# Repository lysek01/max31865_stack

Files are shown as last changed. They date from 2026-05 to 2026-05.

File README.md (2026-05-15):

# MAX31865 Stack

A stackable carrier board for the **Adafruit MAX31865** RTD-to-digital
converter. Each board hosts up to **8 MAX31865 modules** and multiple boards
can be stacked on brass standoffs to scale the channel count without changing
the wiring to the host.

<p align="center">
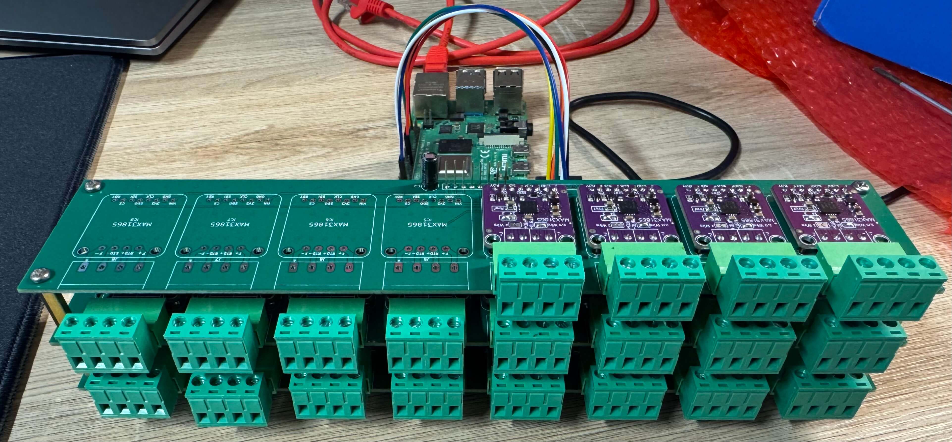
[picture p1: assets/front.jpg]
Front view of the assembled stack
  
</p>

## Overview

Each MAX31865 from Adafruit is an excellent PT100/PT1000 front-end, but
wiring more than a handful of them by hand is tedious and error-prone — every
module needs power, an SPI bus and its own chip-select line.

This project solves that with a carrier PCB that:

- mounts up to **8 plug-in MAX31865 modules** per board,
- brings out a **4-pin pluggable terminal block** per channel for the RTD
  sensor (2/3/4-wire compatible),
- shares one SPI bus across all modules,
- generates individual chip-select signals from a single **PCF8574 I2C
  expander**, so only a handful of signals (SDA, SCL, MOSI, MISO, SCK plus
  3.3 V/GND) ever leave the stack regardless of how many boards are stacked,
- **stacks vertically** on brass M3 standoffs through stackable pin headers
  that pass the bus straight through, so the wiring from the Raspberry Pi
  goes to a single **8-pin JST XH** connector on the bottom board and every
  board above it is simply plugged into the one below.

With the default I2C address range (0x20–0x27) the stack supports
**up to 8 boards = 64 RTD channels** from a single Raspberry Pi.

<p align="center">
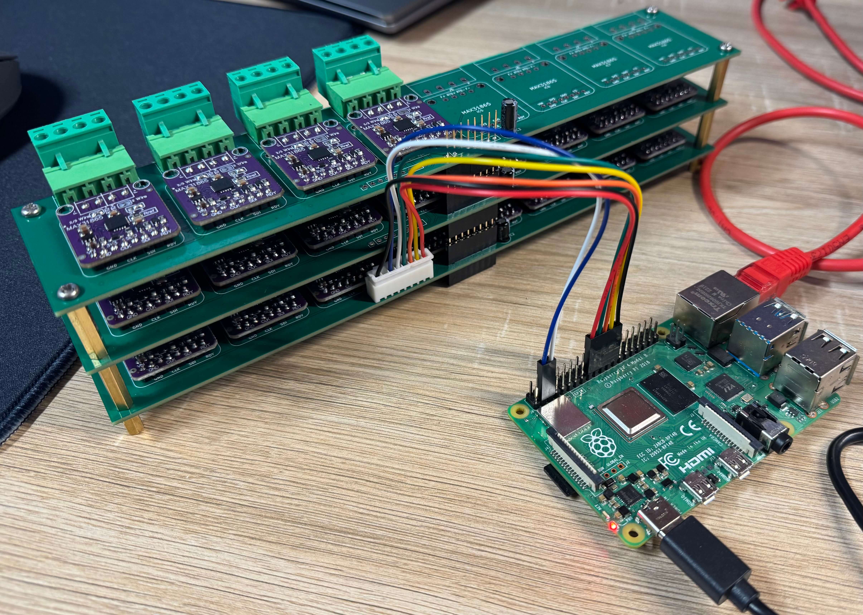
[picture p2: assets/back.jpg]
Stacked boards connected to a Raspberry Pi
  
</p>

## Features

- Up to **8 channels per board**, scalable to **64 channels** per stack.
- Pluggable green terminal blocks for each sensor — sensors can be swapped
  without unsoldering or disturbing the stack.
- **2-, 3- and 4-wire RTD** wiring supported (selected per-module on the
  Adafruit board itself).
- Works with both **PT100** and **PT1000** modules; selectable in software.
- Connects to the host with a single **8-pin JST XH** cable on the bottom
  board; the rest of the stack is bussed through stackable pin headers.
- KiCad sources and JLCPCB production files included.
- Reference Python driver included that auto-detects expanders and modules,
  reads all channels in continuous mode and prints fault-decoded
  measurements.

## Hardware

### Block diagram

```
                              JST XH 8-pin
                                   │
                                   ▼
  Raspberry Pi ──── Board #1 (bottom) ──┐
                    Board #2            │  stacked through
                    Board #N            │  pass-through pin headers
                    ──────────────────  ┘  (I2C + SPI + power)
                         │
        ┌────────────────┼────────────────┐
        ▼                ▼                ▼
     PCF8574          PCF8574          PCF8574
      0x25             0x26             0x27
        │                │                │
        ▼                ▼                ▼
     8x CS            8x CS            8x CS
        │                │                │
        ▼                ▼                ▼
    8x MAX31865      8x MAX31865      8x MAX31865

  SPI bus (SCK, MOSI, MISO) is shared across every MAX31865 on every board.
  CS for each module is driven by one PCF8574 output.
```

The PCF8574 expander on each board takes the I2C address selected by the
jumpers `JP1` / `JP2` / `JP3` (PCF8574 address bits A0/A1/A2). This is how
each board in the stack gets its own unique address — and therefore its own
set of 8 chip-select lines.

<p align="center">
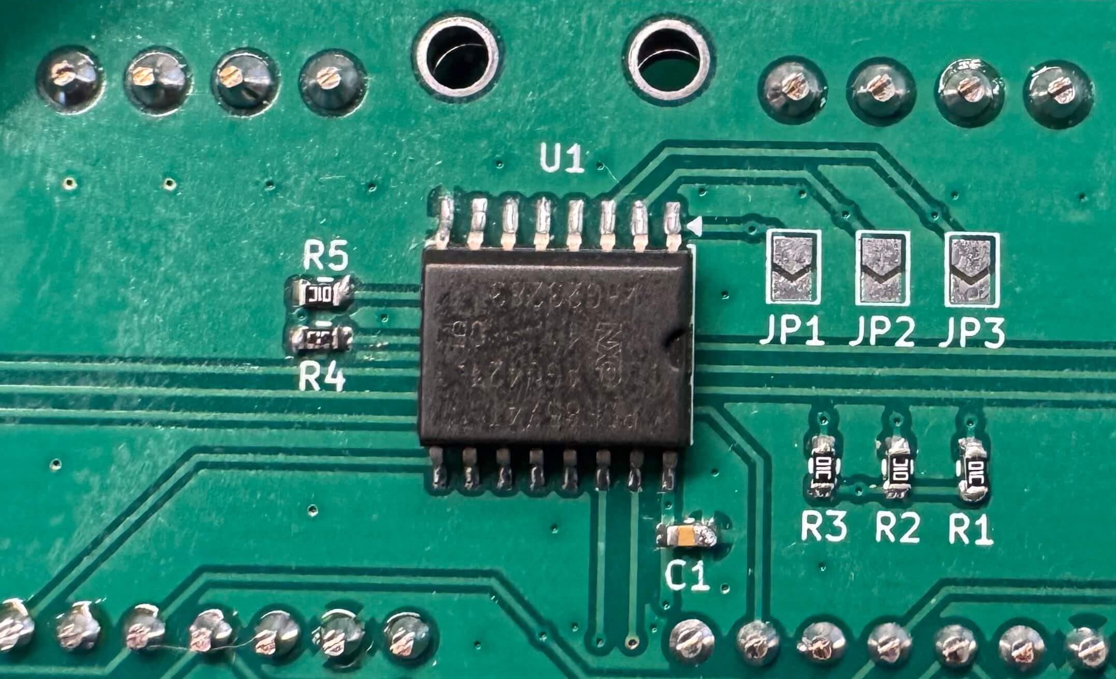
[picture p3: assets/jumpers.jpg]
Bottom-side closeup: PCF8574 and address jumpers JP1/JP2/JP3
  
</p>

### Per-board contents

| Reference | Part |
|---|---|
| U1 | PCF8574 I2C 8-bit I/O expander (SOIC-16) |
| 8x | Sockets for Adafruit MAX31865 PT100/PT1000 breakout |
| 8x | 4-pin pluggable terminal blocks (5.08 mm, RTD sensor) |
| JP1–JP3 | I2C address jumpers (A0, A1, A2) |
| J1 | 8-pin JST XH connector (host link, populated on bottom board only) |
| — | 8-pin stackable pin headers — bus pass-through between boards |

### Stacking

Boards stack mechanically on **brass M3 standoffs** and electrically through
**stackable 8-pin pin headers**, which pass the I2C, SPI and power signals
straight up through the stack.

The bottom board carries the **8-pin JST XH connector (J1)** that is wired
to the Raspberry Pi. Any boards above it inherit the same bus through the
pass-through headers — no extra cabling is needed when adding a board.

Each board only needs a unique PCF8574 address, set with the three address
jumpers (`JP1`/`JP2`/`JP3`).

<p align="center">
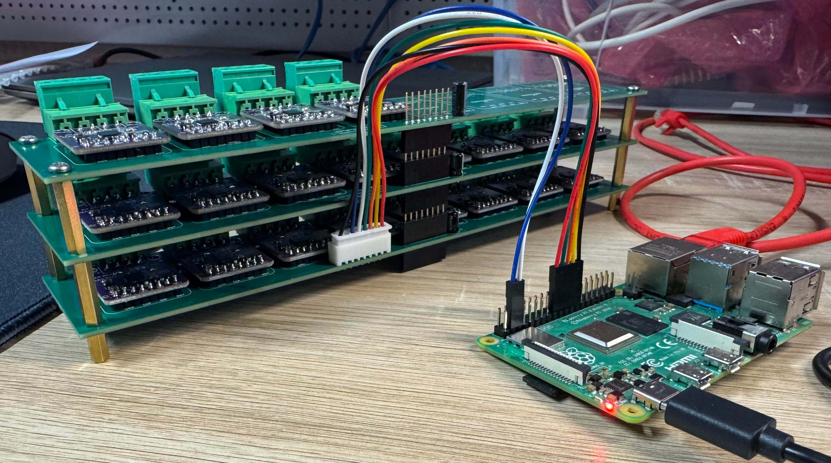
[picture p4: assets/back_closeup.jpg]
Stack closeup showing the JST XH on the bottom board and pass-through headers
  
</p>

### Sensor wiring

Each channel exposes a 4-pin pluggable terminal block matching the Adafruit
MAX31865 module pinout. Use the Adafruit module's own solder jumpers to
configure 2-, 3- or 4-wire mode.

> ⚠️ Use a **reference resistor matched to your RTD**:
> - PT100  → 430 Ω  (default on Adafruit boards)
> - PT1000 → 4300 Ω
>
> Mixing PT1000 sensors with the default 430 Ω reference (or vice versa)
> will not work correctly.

## Connecting to a Raspberry Pi

The bottom board of the stack carries an **8-pin JST XH connector (J1)**
that links the whole stack to the Raspberry Pi. Each pin of the connector is
labelled on the board's silkscreen — wire each labelled signal to the
matching Raspberry Pi GPIO header pin according to the table below.

The diagram below highlights the relevant pin groups on the 40-pin header:
the **I²C** group (SDA / SCL) and the **SPI** group (MOSI / MISO / SCLK,
together with the 3V3 and GND pins that are convenient to use for powering
the stack).

<p align="center">
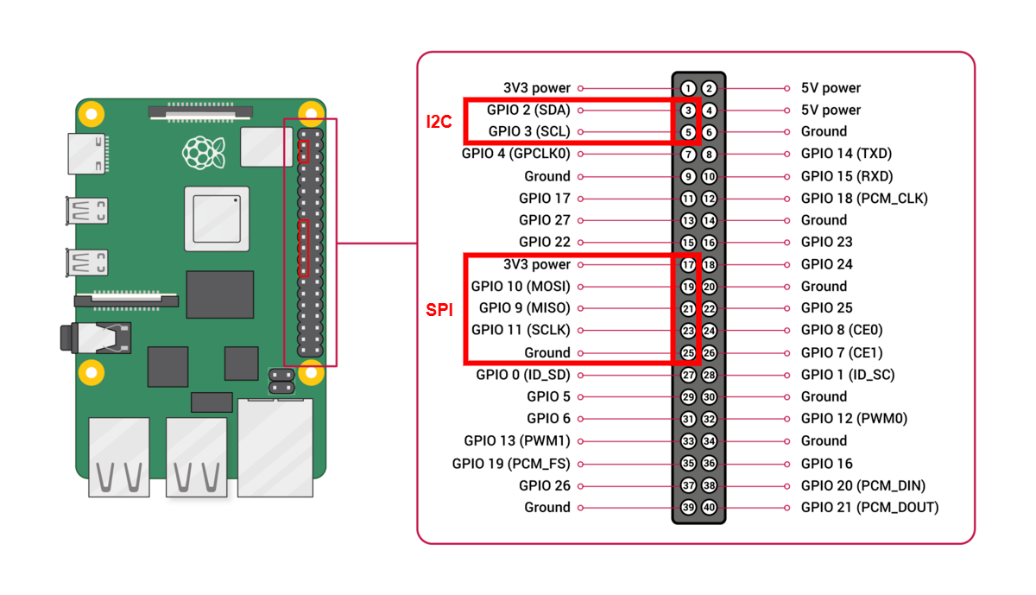
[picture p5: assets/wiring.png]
Raspberry Pi 40-pin GPIO header with the I2C and SPI pin groups highlighted
  
</p>

Counting from the **left edge** of the JST XH connector (pin 1) to the
right (pin 8):

| JST pin | Silkscreen | Function | RPi physical pin | RPi BCM GPIO |
|:---:|:---:|:---|:---:|:---:|
| 1 | `GND` | Ground | 6 | — |
| 2 | `GND` | Ground (redundant) | any GND | — |
| 3 | `SDA` | I²C data (PCF8574) | 3 | GPIO 2 |
| 4 | `SCL` | I²C clock (PCF8574) | 5 | GPIO 3 |
| 5 | `MOSI` | SPI MOSI (MAX31865) | 19 | GPIO 10 |
| 6 | `MISO` | SPI MISO (MAX31865) | 21 | GPIO 9 |
| 7 | `CLK` | SPI clock (MAX31865) | 23 | GPIO 11 |
| 8 | `VCC` | Logic supply | 1 (3V3) | — |

Both `GND` pins on the connector (pins 1 and 2) are tied to the same ground
net on the board. In practice you only need to wire one of them on your
cable — the other can be left unconnected or used as a spare.

> ℹ️ The Adafruit MAX31865 breakout accepts 3 V–5 V on `VIN`, but its logic
> level must match `VIN`. When wiring to a Raspberry Pi (3.3 V GPIO), power
> the stack from the Pi's **3V3** pin — that keeps `VCC` and the SPI / I²C
> logic at the same level and matches the GPIO directly without a level
> shifter.

> ℹ️ The "RPi physical pin" column uses the 1–40 header numbering printed
> on Raspberry Pi pinout cards. "BCM GPIO" is the numbering reported by
> `pinout` and used in `/sys/class/gpio`. Both refer to the same physical
> pad; pick whichever is more convenient.

When more than one board is in the stack, the same signals propagate
upwards through the stackable pin headers — only this single JST cable goes
to the Pi.

## Software

A reference reader is provided in [`software/read.py`](software/read.py).
It runs on Linux (tested on Raspberry Pi OS) and:

1. Scans I2C addresses 0x20–0x27 for PCF8574 expanders.
2. For every CS pin on every expander, probes for a MAX31865 by writing and
   reading back the CONFIG and threshold registers.
3. Starts continuous conversion on every detected module.
4. Periodically reads all channels, decodes any fault bits, converts the raw
   ADC value to resistance and then to temperature using the
   **Callendar–Van Dusen** equation (closed-form for t ≥ 0 °C, bisection of
   the full 4-coefficient form for t < 0 °C).

### Requirements

- Raspberry Pi (or another Linux SBC) with I2C and SPI enabled
- Python 3.7+
- Python packages listed in [`software/requirements.txt`](software/requirements.txt):
  ```bash
  pip install -r software/requirements.txt
  ```

### Enabling I2C and SPI on Raspberry Pi

Both buses are disabled by default on a fresh Raspberry Pi OS image. Enable
them with `raspi-config`:

```bash
sudo raspi-config
```

Then navigate to **Interface Options → I2C → Enable** and
**Interface Options → SPI → Enable**, and reboot.

After the reboot you should see the devices in `/dev`:

```bash
ls /dev/i2c-* /dev/spidev*
# /dev/i2c-1  /dev/spidev0.0  /dev/spidev0.1
```

A quick sanity check that the boards are visible on the I2C bus:

```bash
sudo apt install i2c-tools
i2cdetect -y 1
```

You should see the PCF8574 expanders show up in the 0x20–0x27 range — one
address per board in the stack.

### Configuration

Open [`software/read.py`](software/read.py) and adjust the constants at the
top of the file:

| Constant | Meaning |
|---|---|
| `I2C_BUS` | I2C bus index (`1` on Raspberry Pi) |
| `SPI_BUS`/`SPI_DEVICE` | SPI bus/CS index used to talk to the modules |
| `SPI_SPEED_HZ` | SPI clock; 100 kHz is conservative and reliable |
| `THREE_WIRE` | `True` for 3-wire RTDs, `False` for 2/4-wire |
| `FILTER_50HZ` | `True` in 50 Hz mains regions, `False` for 60 Hz |
| `RNOMINAL` | `100.0` for PT100, `1000.0` for PT1000 |
| `DEFAULT_RREF` | Reference resistor on the Adafruit module (430 / 4300 Ω) |
| `PRINT_INTERVAL` | Seconds between measurement scans |

### Running

```bash
python3 software/read.py
```

Example output:

```
MAX31865 multi-board reader
==========================
I2C bus:       1
SPI bus/dev:   0.0
...

Scanning for PCF8574 expanders...
  expander found: 0x25
  expander found: 0x26
  expander found: 0x27

Detecting MAX31865 modules behind each CS pin...
Expander 0x25:
  P0: MAX31865 OK      CONFIG OK 0x91, marker OK
  ...

============================================================
2026-05-15 14:23:01
CH00 E0x25-P0: OK        23.451 C   R=109.123 Ohm   raw=8412
CH01 E0x25-P1: OK        23.802 C   R=109.260 Ohm   raw=8423
...
scan time: 142.318 ms   OK=24   NOT_OK=0
```

## Repository layout

```
.
├── assets/         photos of the assembled stack
├── hardware/       KiCad project (schematic, PCB) + JLCPCB production files
├── software/       Python reader for Raspberry Pi
├── LICENSE         MIT
└── README.md       you are here
```

## License

Released under the [MIT License](LICENSE). The Adafruit MAX31865 module is a
separate product; consult Adafruit's own documentation and licensing for the
module itself.

## Author

Martin Lysek — 2026.

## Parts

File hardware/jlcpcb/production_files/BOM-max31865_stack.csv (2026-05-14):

Comment | Designator | Footprint | LCSC | Quantity
PCF8574T | U1 | SOIC-16W_7.5x10.3mm_P1.27mm |  | 1
Conn_01x08_Pin | J10 | PinHeader_1x08_P2.54mm_Vertical |  | 1
Conn_01x04_Pin | J8 | PhoenixContact_MSTBA_2,5_4-G-5,08_1x04_P5.08mm_Horizontal |  | 1
Conn_01x04_Pin | J7 | PhoenixContact_MSTBA_2,5_4-G-5,08_1x04_P5.08mm_Horizontal |  | 1
Conn_01x04_Pin | J6 | PhoenixContact_MSTBA_2,5_4-G-5,08_1x04_P5.08mm_Horizontal |  | 1
Conn_01x04_Pin | J5 | PhoenixContact_MSTBA_2,5_4-G-5,08_1x04_P5.08mm_Horizontal |  | 1
Conn_01x04_Pin | J4 | PhoenixContact_MSTBA_2,5_4-G-5,08_1x04_P5.08mm_Horizontal |  | 1
Conn_01x04_Pin | J3 | PhoenixContact_MSTBA_2,5_4-G-5,08_1x04_P5.08mm_Horizontal |  | 1
Conn_01x04_Pin | J2 | PhoenixContact_MSTBA_2,5_4-G-5,08_1x04_P5.08mm_Horizontal |  | 1
Conn_01x04_Pin | J1 | PhoenixContact_MSTBA_2,5_4-G-5,08_1x04_P5.08mm_Horizontal |  | 1
Conn_01x08_Pin | J9 | PinHeader_1x08_P2.54mm_Vertical |  | 1
MAX31865 | IC1 | Adafruit_MAX31865 |  | 1
MAX31865 | IC2 | Adafruit_MAX31865 |  | 1
MAX31865 | IC7 | Adafruit_MAX31865 |  | 1
MAX31865 | IC5 | Adafruit_MAX31865 |  | 1
MAX31865 | IC3 | Adafruit_MAX31865 |  | 1
MAX31865 | IC4 | Adafruit_MAX31865 |  | 1
MAX31865 | IC8 | Adafruit_MAX31865 |  | 1
MAX31865 | IC6 | Adafruit_MAX31865 |  | 1
4.7k | R5 | R_0603_1608Metric |  | 1
4.7k | R4 | R_0603_1608Metric |  | 1
100n | C1 | C_0603_1608Metric |  | 1
10k | R2 | R_0603_1608Metric |  | 1
47u | C2 | C_Radial_D5.0mm_H7.0mm_P2.00mm |  | 1
10k | R1 | R_0603_1608Metric |  | 1
10k | R3 | R_0603_1608Metric |  | 1

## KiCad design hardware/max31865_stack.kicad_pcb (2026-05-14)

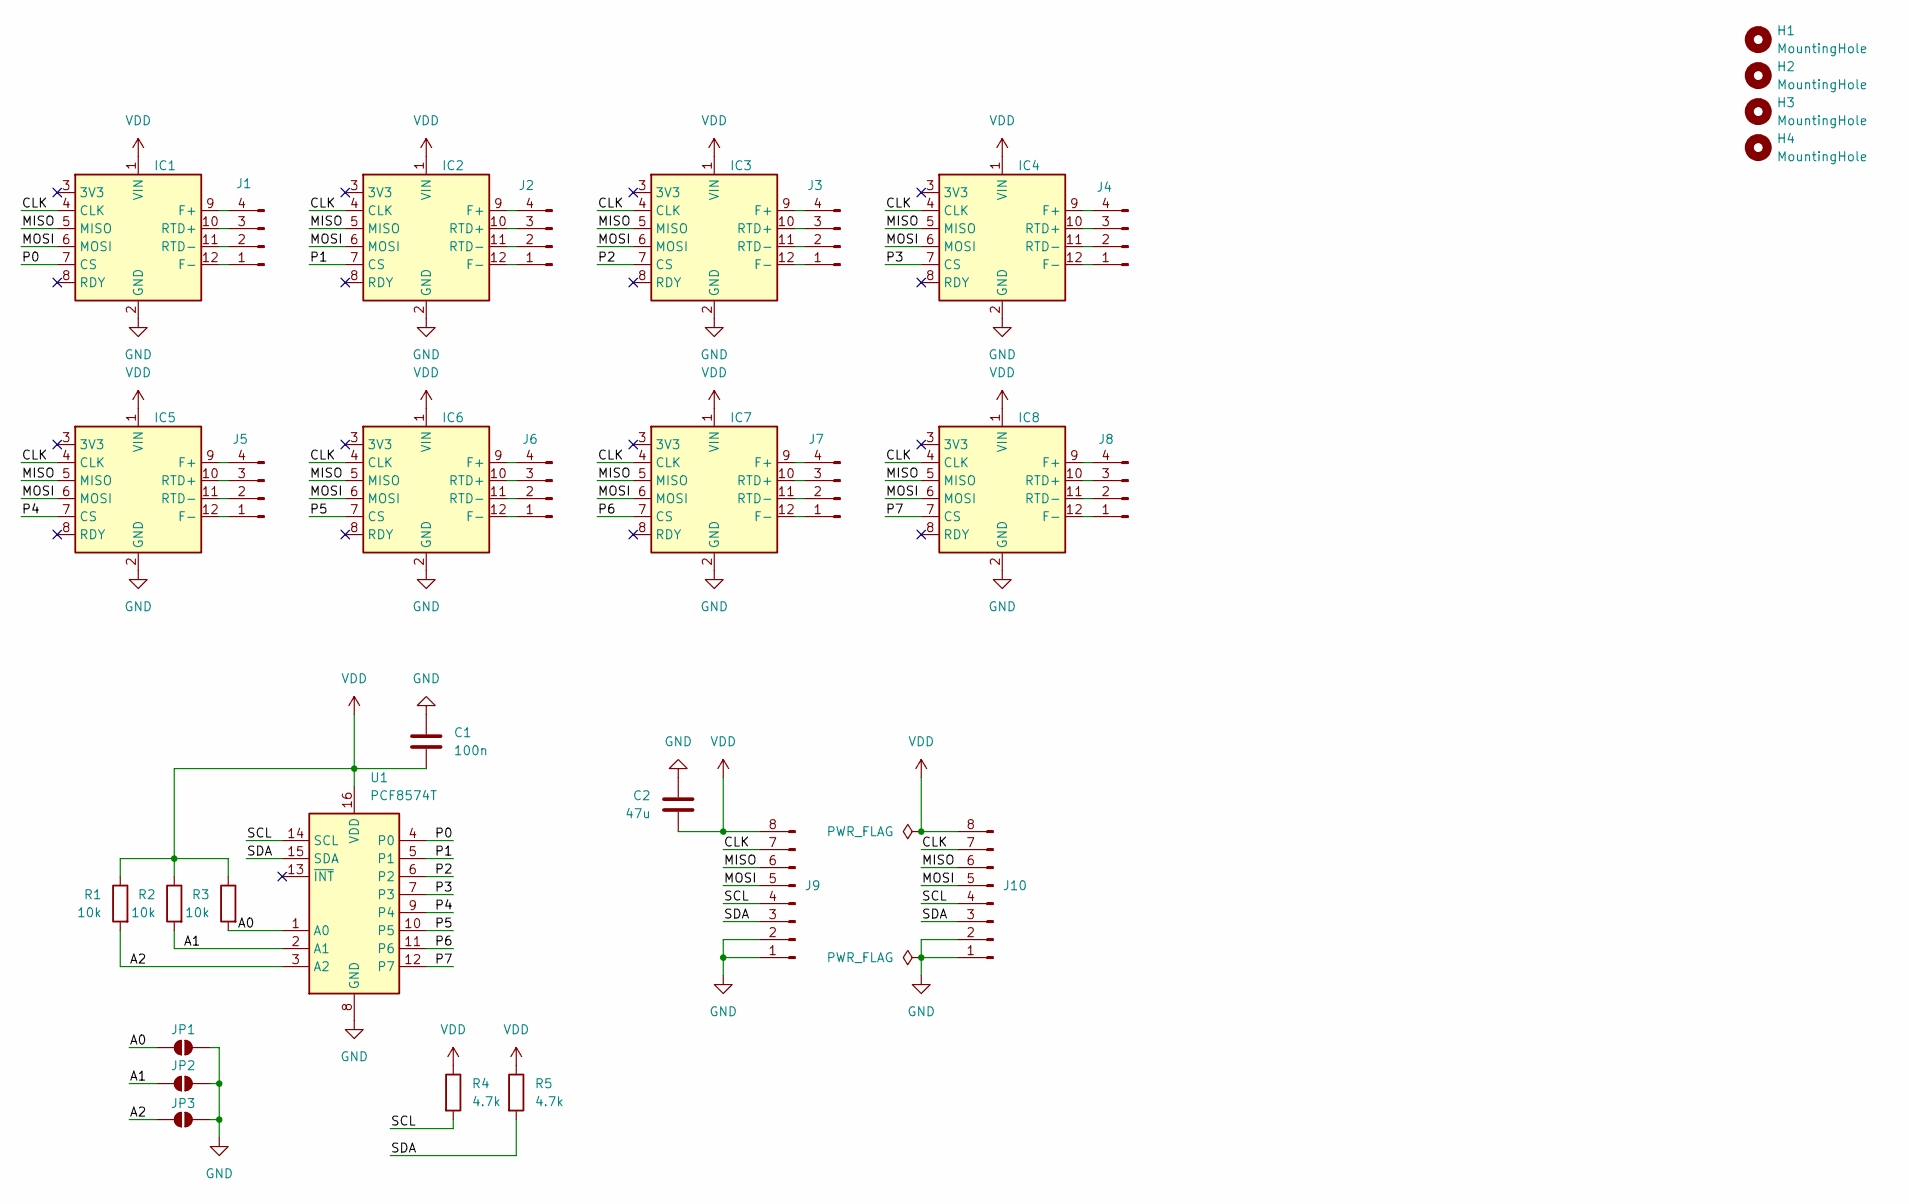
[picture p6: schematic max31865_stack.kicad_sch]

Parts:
C1: 100n; C_0603_1608Metric
C2: 47u; C_Radial_D5.0mm_H7.0mm_P2.00mm
H1, H2, H3, H4: MountingHole; MountingHole_3.2mm_M3
IC1, IC2, IC3, IC4, IC5, IC6, IC7, IC8: MAX31865; Adafruit_MAX31865
J1, J2, J3, J4, J5, J6, J7, J8: Conn_01x04_Pin; PhoenixContact_MSTBA_2,5_4-G-5,08_1x04_P5.08mm_Horizontal
J9, J10: Conn_01x08_Pin; PinHeader_1x08_P2.54mm_Vertical
JP1, JP2, JP3: SolderJumper_2_Open; SolderJumper-2_P1.3mm_Open_TrianglePad1.0x1.5mm
R1, R2, R3: 10k; R_0603_1608Metric
R4, R5: 4.7k; R_0603_1608Metric
U1: PCF8574T; SOIC-16W_7.5x10.3mm_P1.27mm

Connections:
/A0: JP1.1 (A), R3.2, U1.1 (A0)
/A1: JP2.1 (A), R2.2, U1.2 (A1)
/A2: JP3.1 (A), R1.2, U1.3 (A2)
/CLK: IC1.4 (CLK), IC2.4 (CLK), IC3.4 (CLK), IC4.4 (CLK), IC5.4 (CLK), IC6.4 (CLK), IC7.4 (CLK), IC8.4 (CLK), J9.7, J10.7
/MISO: IC1.5 (MISO), IC2.5 (MISO), IC3.5 (MISO), IC4.5 (MISO), IC5.5 (MISO), IC6.5 (MISO), IC7.5 (MISO), IC8.5 (MISO), J9.6, J10.6
/MOSI: IC1.6 (MOSI), IC2.6 (MOSI), IC3.6 (MOSI), IC4.6 (MOSI), IC5.6 (MOSI), IC6.6 (MOSI), IC7.6 (MOSI), IC8.6 (MOSI), J9.5, J10.5
/P0: IC1.7 (CS), U1.4 (P0)
/P1: IC2.7 (CS), U1.5 (P1)
/P2: IC3.7 (CS), U1.6 (P2)
/P3: IC4.7 (CS), U1.7 (P3)
/P4: IC5.7 (CS), U1.9 (P4)
/P5: IC6.7 (CS), U1.10 (P5)
/P6: IC7.7 (CS), U1.11 (P6)
/P7: IC8.7 (CS), U1.12 (P7)
/SCL: J9.4, J10.4, R4.2, U1.14 (SCL)
/SDA: J9.3, J10.3, R5.2, U1.15 (SDA)
GND: C1.1, C2.1, IC1.2 (GND), IC2.2 (GND), IC3.2 (GND), IC4.2 (GND), IC5.2 (GND), IC6.2 (GND), IC7.2 (GND), IC8.2 (GND), J9.1, J9.2, J10.1, J10.2, JP1.2 (B), JP2.2 (B), JP3.2 (B), U1.8 (GND)
unnamed: IC1.9 (F+), J1.4
unnamed: IC1.12 (F-), J1.1
unnamed: IC1.10 (RTD+), J1.3
unnamed: IC1.11 (RTD-), J1.2
unnamed: IC2.9 (F+), J2.4
unnamed: IC2.12 (F-), J2.1
unnamed: IC2.10 (RTD+), J2.3
unnamed: IC2.11 (RTD-), J2.2
unnamed: IC3.9 (F+), J3.4
unnamed: IC3.12 (F-), J3.1
unnamed: IC3.10 (RTD+), J3.3
unnamed: IC3.11 (RTD-), J3.2
unnamed: IC4.9 (F+), J4.4
unnamed: IC4.12 (F-), J4.1
unnamed: IC4.10 (RTD+), J4.3
unnamed: IC4.11 (RTD-), J4.2
unnamed: IC5.9 (F+), J5.4
unnamed: IC5.12 (F-), J5.1
unnamed: IC5.10 (RTD+), J5.3
unnamed: IC5.11 (RTD-), J5.2
unnamed: IC6.9 (F+), J6.4
unnamed: IC6.12 (F-), J6.1
unnamed: IC6.10 (RTD+), J6.3
unnamed: IC6.11 (RTD-), J6.2
unnamed: IC7.9 (F+), J7.4
unnamed: IC7.12 (F-), J7.1
unnamed: IC7.10 (RTD+), J7.3
unnamed: IC7.11 (RTD-), J7.2
unnamed: IC8.9 (F+), J8.4
unnamed: IC8.12 (F-), J8.1
unnamed: IC8.10 (RTD+), J8.3
unnamed: IC8.11 (RTD-), J8.2
VDD: C1.2, C2.2, IC1.1 (VIN), IC2.1 (VIN), IC3.1 (VIN), IC4.1 (VIN), IC5.1 (VIN), IC6.1 (VIN), IC7.1 (VIN), IC8.1 (VIN), J9.8, J10.8, R1.1, R2.1, R3.1, R4.1, R5.1, U1.16 (VDD)

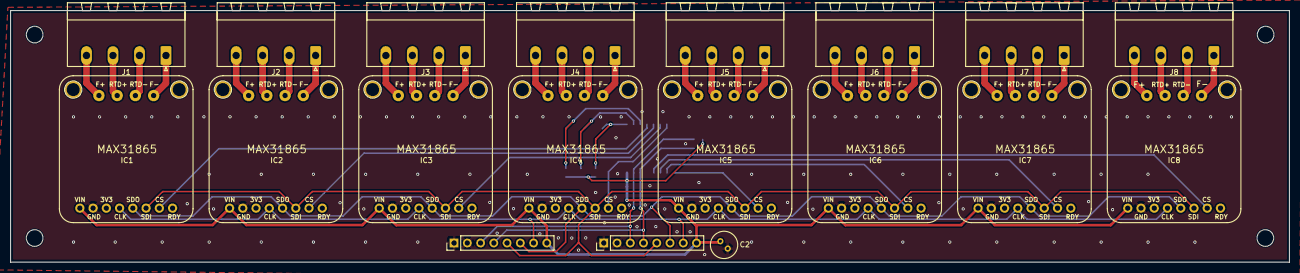
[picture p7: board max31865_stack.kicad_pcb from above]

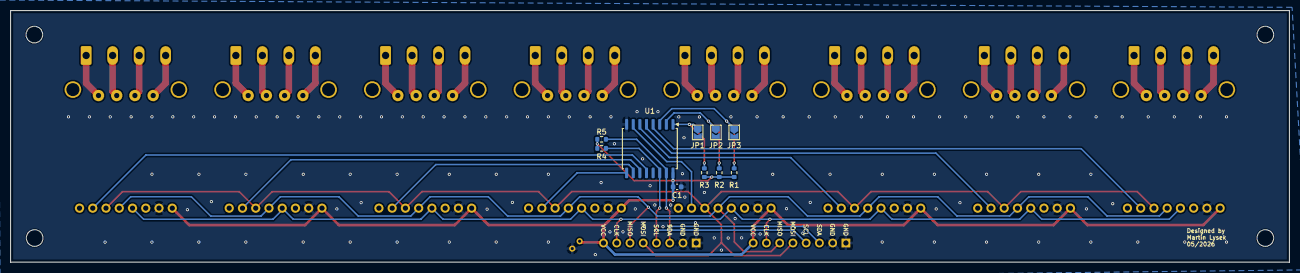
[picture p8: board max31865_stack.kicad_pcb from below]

Board: 2 copper layers, 245.2 x 48.2 mm, 33 parts (10 on the bottom side), 50 nets.

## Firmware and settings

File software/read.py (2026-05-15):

#!/usr/bin/env python3

import time
import math
import smbus2
import spidev


# ============================================================
# CONFIGURATION
# ============================================================

I2C_BUS = 1

# PCF8574 typically uses 0x20-0x27.
# Currently installed: 0x25, 0x26, 0x27.
PCF_SCAN_ADDRESSES = range(0x20, 0x28)

SPI_BUS = 0
SPI_DEVICE = 0
SPI_SPEED_HZ = 100_000
SPI_MODE = 1

# MAX31865 / RTD settings
THREE_WIRE = True
FILTER_50HZ = True

# PT100  = 100.0
# PT1000 = 1000.0
RNOMINAL = 100.0

# PT100  MAX31865 module typically uses 430 ohm reference
# PT1000 MAX31865 module typically uses 4300 ohm reference
DEFAULT_RREF = 430.0

# Measurement print interval (seconds)
PRINT_INTERVAL = 1.0

# Discard the first N scans after entering continuous mode
WARMUP_SCANS = 3

# Automatically clear latched fault bits.
# Important mainly when sensors are hot-swapped during operation.
AUTO_CLEAR_FAULTS = True

# If True, every detected MAX31865 module is printed,
# even when no sensor is connected to it.
SHOW_FAILED_CHANNELS = True

# To print only healthy channels, set:
# SHOW_FAILED_CHANNELS = False


# ============================================================
# MAX31865 REGISTERS
# ============================================================

REG_CONFIG = 0x00
REG_RTD_MSB = 0x01
REG_RTD_LSB = 0x02
REG_HIGH_FAULT_MSB = 0x03
REG_HIGH_FAULT_LSB = 0x04
REG_LOW_FAULT_MSB = 0x05
REG_LOW_FAULT_LSB = 0x06
REG_FAULT_STATUS = 0x07

CONFIG_BIAS = 0x80
CONFIG_MODE_AUTO = 0x40
CONFIG_1SHOT = 0x20
CONFIG_3WIRE = 0x10
CONFIG_FAULT_CLEAR = 0x02
CONFIG_FILTER_50HZ = 0x01

# Raw RTD ADC code (15-bit) above which the reading is treated as
# saturated / invalid (close to full scale = open or shorted input).
RAW_NEAR_MAX = 32760


# ============================================================
# HELPERS
# ============================================================

def config_base():
    cfg = CONFIG_BIAS

    if THREE_WIRE:
        cfg |= CONFIG_3WIRE

    if FILTER_50HZ:
        cfg |= CONFIG_FILTER_50HZ

    return cfg


def decode_fault(fault):
    if fault == 0:
        return "OK"

    messages = []

    if fault & 0x80:
        messages.append("RTD high threshold")
    if fault & 0x40:
        messages.append("RTD low threshold")
    if fault & 0x20:
        messages.append("REFIN- > 0.85 x VBIAS")
    if fault & 0x10:
        messages.append("REFIN- < 0.85 x VBIAS AND FORCE- open")
    if fault & 0x08:
        messages.append("RTDIN- < 0.85 x VBIAS AND FORCE- open")
    if fault & 0x04:
        messages.append("over/under voltage")

    if not messages:
        messages.append(f"unknown fault 0x{fault:02X}")

    return ", ".join(messages)


def resistance_to_temperature_celsius(rtd_resistance, rnominal=100.0):
    """
    Convert PT100/PT1000 resistance to temperature using
    the Callendar-Van Dusen equation.
    """

    a = 3.9083e-3
    b = -5.775e-7

    discriminant = a * a - 4 * b * (1 - rtd_resistance / rnominal)

    # Analytical branch for t >= 0 C
    if discriminant >= 0:
        temp = (-a + math.sqrt(discriminant)) / (2 * b)
        if temp >= 0:
            return temp

    # Bisection branch for the sub-zero range (approx -200 to 0 C).
    # Uses the full 4-coefficient CVD form including the C term.
    low = -200.0
    high = 0.0

    for _ in range(50):
        mid = (low + high) / 2.0

        r_mid = rnominal * (
            1
            + a * mid
            + b * mid * mid
            - 4.183e-12 * (mid - 100) * mid * mid * mid
        )

        if r_mid < rtd_resistance:
            low = mid
        else:
            high = mid

    return (low + high) / 2.0


# ============================================================
# MULTI PCF8574 CS CONTROL
# ============================================================

class MultiPCF8574CS:
    def __init__(self, i2c_bus, addresses):
        self.bus = i2c_bus
        self.addresses = list(addresses)

    def all_high(self):
        for addr in self.addresses:
            self.bus.write_byte(addr, 0xFF)

    def select(self, expander_addr, pin):
        """
        Drive every output HIGH on every expander, then pull the selected
        pin LOW on the target expander (active-low chip select).
        """

        for addr in self.addresses:
            if addr == expander_addr:
                state = 0xFF & ~(1 << pin)
            else:
                state = 0xFF

            self.bus.write_byte(addr, state)

    def transfer(self, spi, expander_addr, pin, data):
        """
        Perform one SPI transaction:
        all CS HIGH -> selected CS LOW -> SPI transfer -> all CS HIGH.
        """

        self.select(expander_addr, pin)
        time.sleep(0.0005)

        rx = spi.xfer2(data)

        time.sleep(0.0005)
        self.all_high()
        time.sleep(0.0005)

        return rx


# ============================================================
# MAX31865 SYSTEM
# ============================================================

class MAX31865MultiSystem:
    def __init__(self, spi, cs):
        self.spi = spi
        self.cs = cs

    def write_register(self, expander_addr, pin, reg, value):
        self.cs.transfer(
            self.spi,
            expander_addr,
            pin,
            [reg | 0x80, value & 0xFF],
        )

    def read_registers(self, expander_addr, pin, reg, count):
        rx = self.cs.transfer(
            self.spi,
            expander_addr,
            pin,
            [reg & 0x7F] + [0x00] * count,
        )
        return rx[1:]

    def read_register(self, expander_addr, pin, reg):
        return self.read_registers(expander_addr, pin, reg, 1)[0]

    def set_fault_thresholds(self, expander_addr, pin):
        """
        Set thresholds to full range so the threshold registers themselves
        cannot cause spurious high/low fault flags.
        """

        self.write_register(expander_addr, pin, REG_HIGH_FAULT_MSB, 0xFF)
        self.write_register(expander_addr, pin, REG_HIGH_FAULT_LSB, 0xFF)
        self.write_register(expander_addr, pin, REG_LOW_FAULT_MSB, 0x00)
        self.write_register(expander_addr, pin, REG_LOW_FAULT_LSB, 0x00)

    def clear_faults(self, expander_addr, pin, keep_continuous=False):
        """
        Clear the latched fault bits.

        With keep_continuous=True the auto-conversion mode is preserved
        (re-asserted in the same write). This matters because a bare
        CONFIG_FAULT_CLEAR write would otherwise drop the device out of
        continuous mode.
        """

        cfg = config_base() | CONFIG_FAULT_CLEAR

        if keep_continuous:
            cfg |= CONFIG_MODE_AUTO

        self.write_register(
            expander_addr,
            pin,
            REG_CONFIG,
            cfg,
        )

    def check_max31865_present(self, expander_addr, pin):
        """
        MAX31865 has no WHOAMI register, so presence is verified by:
        1) writing and reading back the CONFIG register
        2) writing and reading back a marker in the threshold registers

        Note: bit D0 of the High Fault Threshold LSB is don't-care and
        reads back as 0, so it is masked out of the comparison.
        """

        expected_cfg = config_base()

        self.write_register(expander_addr, pin, REG_CONFIG, expected_cfg)
        time.sleep(0.005)

        actual_cfg = self.read_register(expander_addr, pin, REG_CONFIG)

        if actual_cfg != expected_cfg:
            return False, (
                f"CONFIG mismatch expected=0x{expected_cfg:02X}, "
                f"read=0x{actual_cfg:02X}"
            )

        marker_a = 0xA0 | (pin & 0x0F)
        # LSB bit D0 is don't-care in MAX31865 threshold LSB registers,
        # so force it to 0 to keep the round-trip comparison stable.
        marker_b = (0x50 | (pin & 0x0F)) & 0xFE

        self.write_register(expander_addr, pin, REG_HIGH_FAULT_MSB, marker_a)
        self.write_register(expander_addr, pin, REG_HIGH_FAULT_LSB, marker_b)

        read_marker = self.read_registers(
            expander_addr,
            pin,
            REG_HIGH_FAULT_MSB,
            2,
        )

        if read_marker[0] != marker_a or (read_marker[1] & 0xFE) != marker_b:
            return (
                False,
                f"marker mismatch expected=0x{marker_a:02X} 0x{marker_b:02X}, "
                f"read=0x{read_marker[0]:02X} 0x{read_marker[1]:02X}"
            )

        self.set_fault_thresholds(expander_addr, pin)
        self.clear_faults(expander_addr, pin, keep_continuous=False)

        return True, f"CONFIG OK 0x{actual_cfg:02X}, marker OK"

    def start_continuous(self, expander_addr, pin):
        """
        Enable continuous / auto-conversion mode.
        """

        self.set_fault_thresholds(expander_addr, pin)

        self.write_register(
            expander_addr,
            pin,
            REG_CONFIG,
            config_base() | CONFIG_MODE_AUTO | CONFIG_FAULT_CLEAR,
        )

        time.sleep(0.01)

    def stop_continuous(self, expander_addr, pin):
        """
        Disable continuous mode; VBIAS stays on as defined by config_base().
        """

        self.write_register(
            expander_addr,
            pin,
            REG_CONFIG,
            config_base(),
        )

    def read_raw_and_fault(self, expander_addr, pin):
        data = self.read_registers(expander_addr, pin, REG_RTD_MSB, 2)

        msb = data[0]
        lsb = data[1]

        raw15 = ((msb << 8) | lsb) >> 1
        fault_bit = lsb & 0x01

        fault = 0x00
        if fault_bit:
            fault = self.read_register(expander_addr, pin, REG_FAULT_STATUS)

        return raw15, fault

    def read_channel(self, module):
        expander_addr = module["expander_addr"]
        pin = module["pin"]
        rref = module["rref"]

        raw15, fault = self.read_raw_and_fault(expander_addr, pin)

        # On fault: clear it while preserving continuous mode,
        # wait briefly, then re-read.
        if AUTO_CLEAR_FAULTS and fault:
            self.clear_faults(expander_addr, pin, keep_continuous=True)
            time.sleep(0.1)

            raw15, fault = self.read_raw_and_fault(expander_addr, pin)

        if fault:
            return {
                "ok": False,
                "raw": raw15,
                "fault": fault,
                "reason": decode_fault(fault),
                "resistance": None,
                "temperature": None,
            }

        if raw15 == 0:
            return {
                "ok": False,
                "raw": raw15,
                "fault": 0x00,
                "reason": "raw=0 (RTD disconnected?)",
                "resistance": None,
                "temperature": None,
            }

        if raw15 >= RAW_NEAR_MAX:
            return {
                "ok": False,
                "raw": raw15,
                "fault": 0x00,
                "reason": "raw near maximum",
                "resistance": None,
                "temperature": None,
            }

        resistance = raw15 * rref / 32768.0
        temperature = resistance_to_temperature_celsius(resistance, RNOMINAL)

        return {
            "ok": True,
            "raw": raw15,
            "fault": 0x00,
            "reason": "OK",
            "resistance": resistance,
            "temperature": temperature,
        }


# ============================================================
# I2C EXPANDER DETECTION
# ============================================================

def scan_pcf8574(i2c):
    found = []

    print("Scanning for PCF8574 expanders...")

    for addr in PCF_SCAN_ADDRESSES:
        try:
            i2c.read_byte(addr)
            found.append(addr)
            print(f"  expander found: 0x{addr:02X}")
        except OSError:
            pass

    if not found:
        print("  no PCF8574 expander found")

    print()
    return found


# ============================================================
# MAX31865 MODULE DETECTION
# ============================================================

def detect_max31865_modules(system, expander_addresses):
    modules = []
    logical_index = 0

    print("Detecting MAX31865 modules behind each CS pin...")

    for expander_addr in expander_addresses:
        print(f"Expander 0x{expander_addr:02X}:")

        for pin in range(8):
            try:
                ok, msg = system.check_max31865_present(expander_addr, pin)

                if ok:
                    module = {
                        "index": logical_index,
                        "name": f"E0x{expander_addr:02X}-P{pin}",
                        "expander_addr": expander_addr,
                        "pin": pin,
                        "rref": DEFAULT_RREF,
                    }
                    modules.append(module)

                    print(f"  P{pin}: MAX31865 OK      {msg}")
                    logical_index += 1
                else:
                    print(f"  P{pin}: ---             {msg}")

            except Exception as e:
                print(f"  P{pin}: ---             read error: {e}")

    print()

    if modules:
        print("Detected MAX31865 modules:")
        for m in modules:
            print(
                f"  CH{m['index']:02d}: "
                f"{m['name']}  "
                f"expander=0x{m['expander_addr']:02X} "
                f"pin=P{m['pin']} "
                f"RREF={m['rref']}"
            )
    else:
        print("No MAX31865 module detected.")

    print()
    return modules


# ============================================================
# MEASUREMENT OUTPUT
# ============================================================

def print_measurement_row(module, result):
    label = f"CH{module['index']:02d} {module['name']}"

    if result["ok"]:
        print(
            f"{label}: OK      "
            f"{result['temperature']:8.3f} C   "
            f"R={result['resistance']:9.3f} Ohm   "
            f"raw={result['raw']}"
        )
    else:
        print(
            f"{label}: NOT OK  "
            f"{result['reason']}   "
            f"raw={result['raw']}   "
            f"fault=0x{result['fault']:02X}"
        )


# ============================================================
# MAIN
# ============================================================

def main():
    print("MAX31865 multi-board reader")
    print("==========================")
    print(f"I2C bus:       {I2C_BUS}")
    print(f"SPI bus/dev:   {SPI_BUS}.{SPI_DEVICE}")
    print(f"SPI speed:     {SPI_SPEED_HZ}")
    print(f"SPI mode:      {SPI_MODE}")
    print(f"3-wire:        {THREE_WIRE}")
    print(f"50Hz filter:   {FILTER_50HZ}")
    print(f"RNOMINAL:      {RNOMINAL} Ohm")
    print(f"default RREF:  {DEFAULT_RREF} Ohm")
    print()

    with smbus2.SMBus(I2C_BUS) as i2c:
        expander_addresses = scan_pcf8574(i2c)

        if not expander_addresses:
            return

        cs = MultiPCF8574CS(i2c, expander_addresses)

        # Safe default state: drive all CS lines HIGH.
        cs.all_high()

        spi = spidev.SpiDev()
        spi.open(SPI_BUS, SPI_DEVICE)
        spi.no_cs = True
        spi.mode = SPI_MODE
        spi.max_speed_hz = SPI_SPEED_HZ

        system = MAX31865MultiSystem(spi, cs)

        modules = []

        try:
            modules = detect_max31865_modules(system, expander_addresses)

            if not modules:
                return

            print("Starting continuous mode on detected modules...")
            for module in modules:
                system.start_continuous(
                    module["expander_addr"],
                    module["pin"],
                )

            time.sleep(0.3)

            print("Discarding warmup scans...")
            for _ in range(WARMUP_SCANS):
                for module in modules:
                    system.read_channel(module)
                time.sleep(0.05)

            print()
            print("Measurement started.")
            print()

            while True:
                print("============================================================")
                print(time.strftime("%Y-%m-%d %H:%M:%S"))

                scan_start = time.perf_counter()
                ok_count = 0
                fail_count = 0

                for module in modules:
                    try:
                        result = system.read_channel(module)

                        if result["ok"]:
                            ok_count += 1
                            print_measurement_row(module, result)
                        else:
                            fail_count += 1
                            if SHOW_FAILED_CHANNELS:
                                print_measurement_row(module, result)

                    except Exception as e:
                        fail_count += 1
                        if SHOW_FAILED_CHANNELS:
                            print(
                                f"CH{module['index']:02d} {module['name']}: "
                                f"NOT OK  read error: {e}"
                            )

                scan_time = time.perf_counter() - scan_start

                print(
                    f"scan time: {scan_time * 1000:.3f} ms   "
                    f"OK={ok_count}   NOT_OK={fail_count}"
                )
                print()

                time.sleep(PRINT_INTERVAL)

        finally:
            print()
            print("Stopping continuous mode and driving all CS lines HIGH...")

            for module in modules:
                try:
                    system.stop_continuous(
                        module["expander_addr"],
                        module["pin"],
                    )
                except Exception:
                    pass

            cs.all_high()
            spi.close()


if __name__ == "__main__":
    main()
